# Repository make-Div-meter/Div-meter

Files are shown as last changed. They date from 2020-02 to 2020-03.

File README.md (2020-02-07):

# 概要
ゲーム・アニメ作品「STEINS;GATE（シュタインズ・ゲート）」に登場する「世界線変動率計測器≪ダイバージェンスメーター≫」を製作する。

## 開発スケジュール
### 第1段階　2020年3月31日
ニキシー管に任意の数字を表示できる状態にする。

### 第2段階
時計・カレンダー機能の実装。

### 第3段階
外部端末とBluetooth等の無線通信を用いて接続し、任意に表示を変化させることができる。

## 表示モード
複数の機能を持たせる。
### DGモード
劇中に登場するダイバージェンスメーターと同じように世界線変動率を8桁のニキシー管に表示する。
### 時計モード
時計としての表示を行う。
表示フォーマットは「HH.mm.ss」
### カレンダーモード
カレンダーとしての表示を行う。
表示フォーマットは「MM.dd...」

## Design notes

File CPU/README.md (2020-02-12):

# CPU
マイコン:ESP32<br>
動作電圧:3.3V<br>

Android appとBluetoothで接続する。<br>
appからESPへの送信データは以下の通り

|フォーマット|説明|
|:-:|:-:|
|SET NUM|数値を即座にNUMに変更する|
|RAND NUM|数値をランダムに切り替えながらNUMに変更する|

Bluetoothシリアル経由で取得した値(整数部1桁+小数点+小数部6桁)をUART経由でGPUに送る。

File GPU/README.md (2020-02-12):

# GPU
ニキシー管をダイナミック点灯させるマイコン
CPUとシリアル通信を行い，内部レジスタに値を保存する。またその内容をニキシー管に表示する．内部レジスタに保存した値はCPUから新しい値が送られてくるまで表示され続ける。

## 要求スペック
### 動作クロック
未定
### ピン数
ニキシー管制御　3+4
I2C　2
UART 2
## 動作電圧
3.3V

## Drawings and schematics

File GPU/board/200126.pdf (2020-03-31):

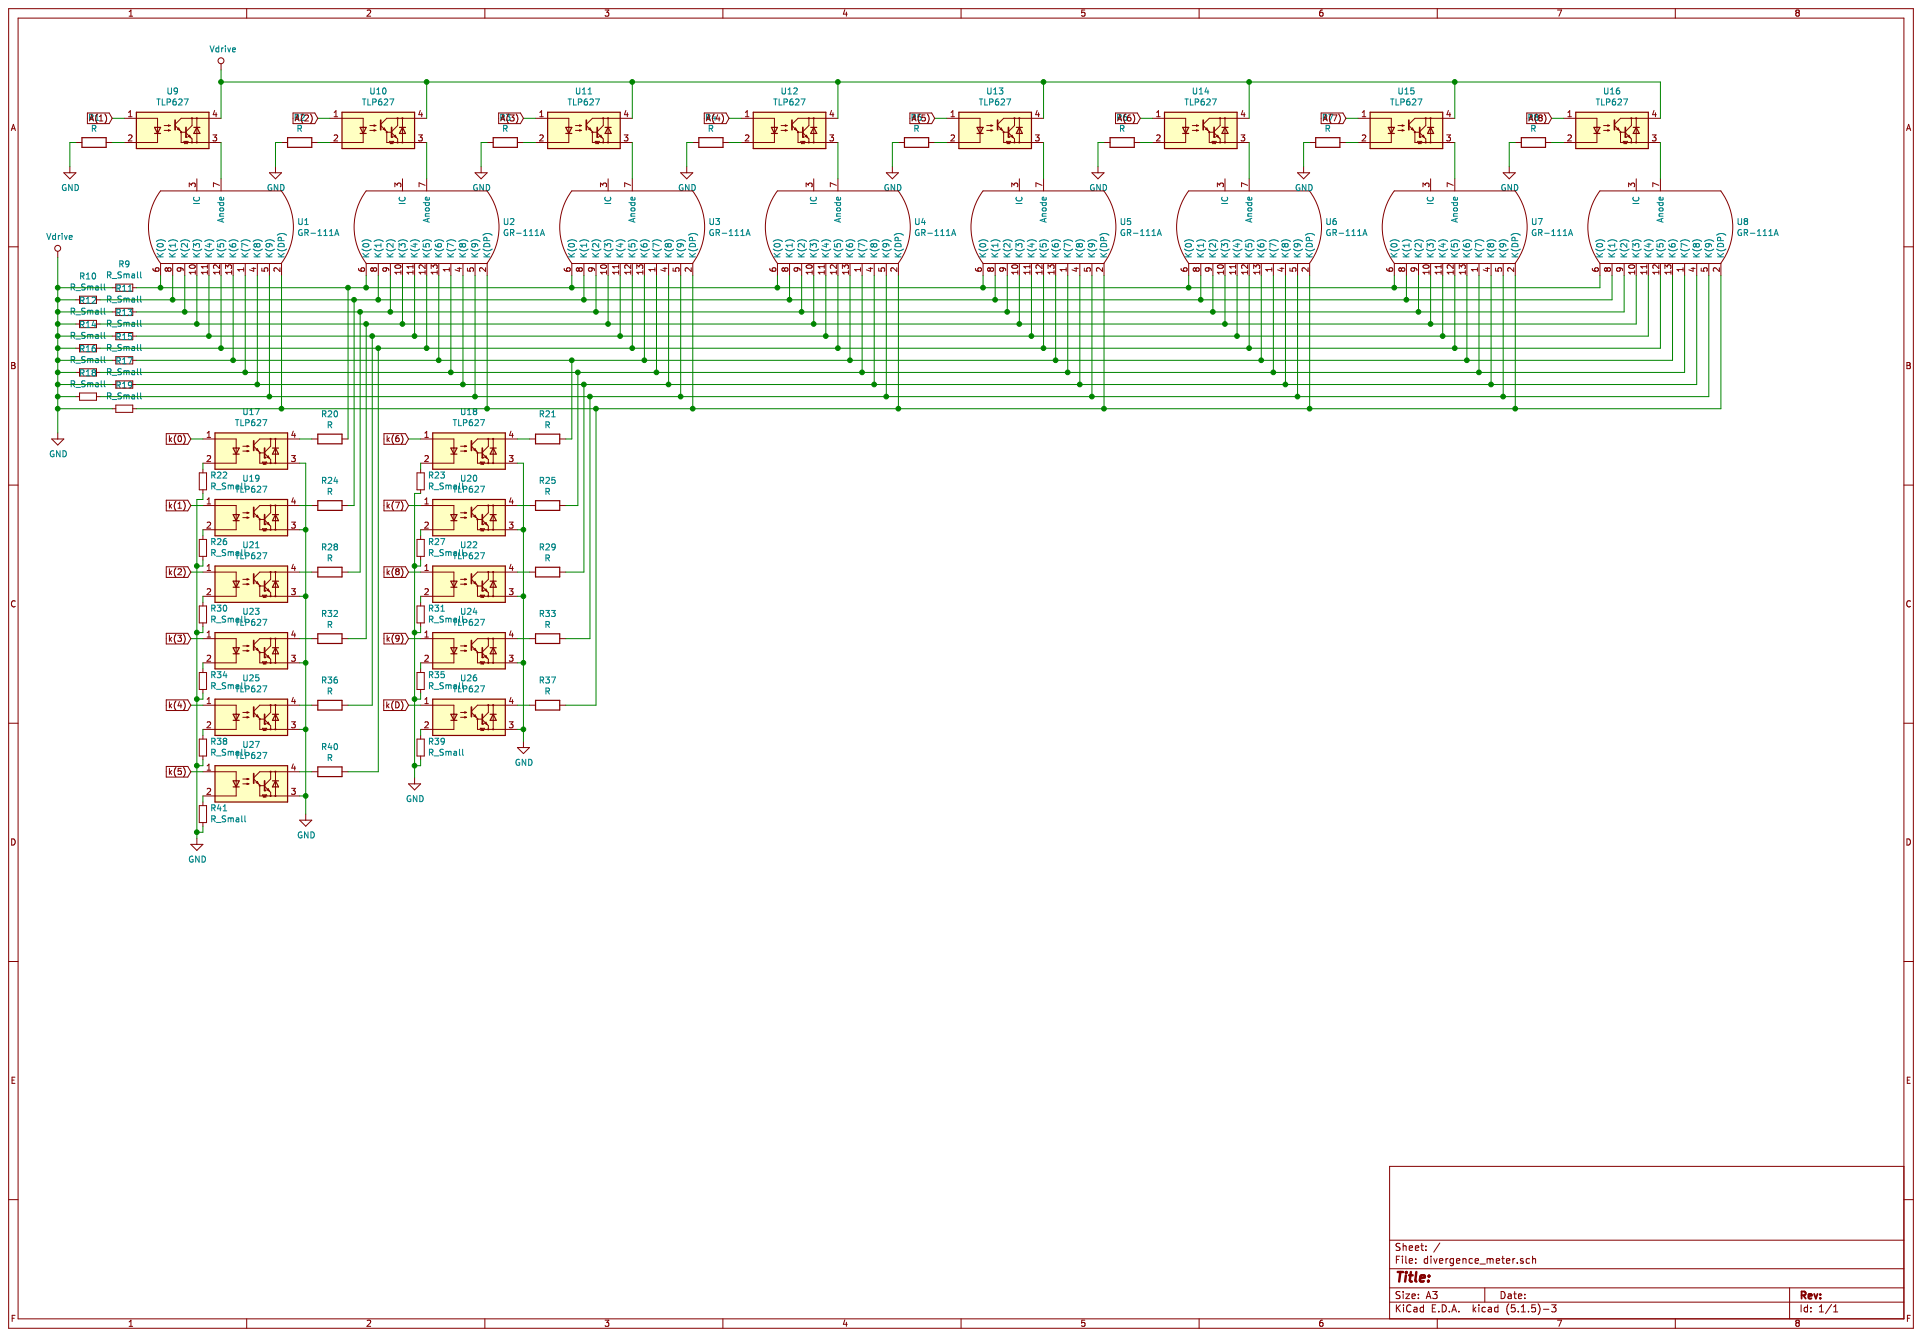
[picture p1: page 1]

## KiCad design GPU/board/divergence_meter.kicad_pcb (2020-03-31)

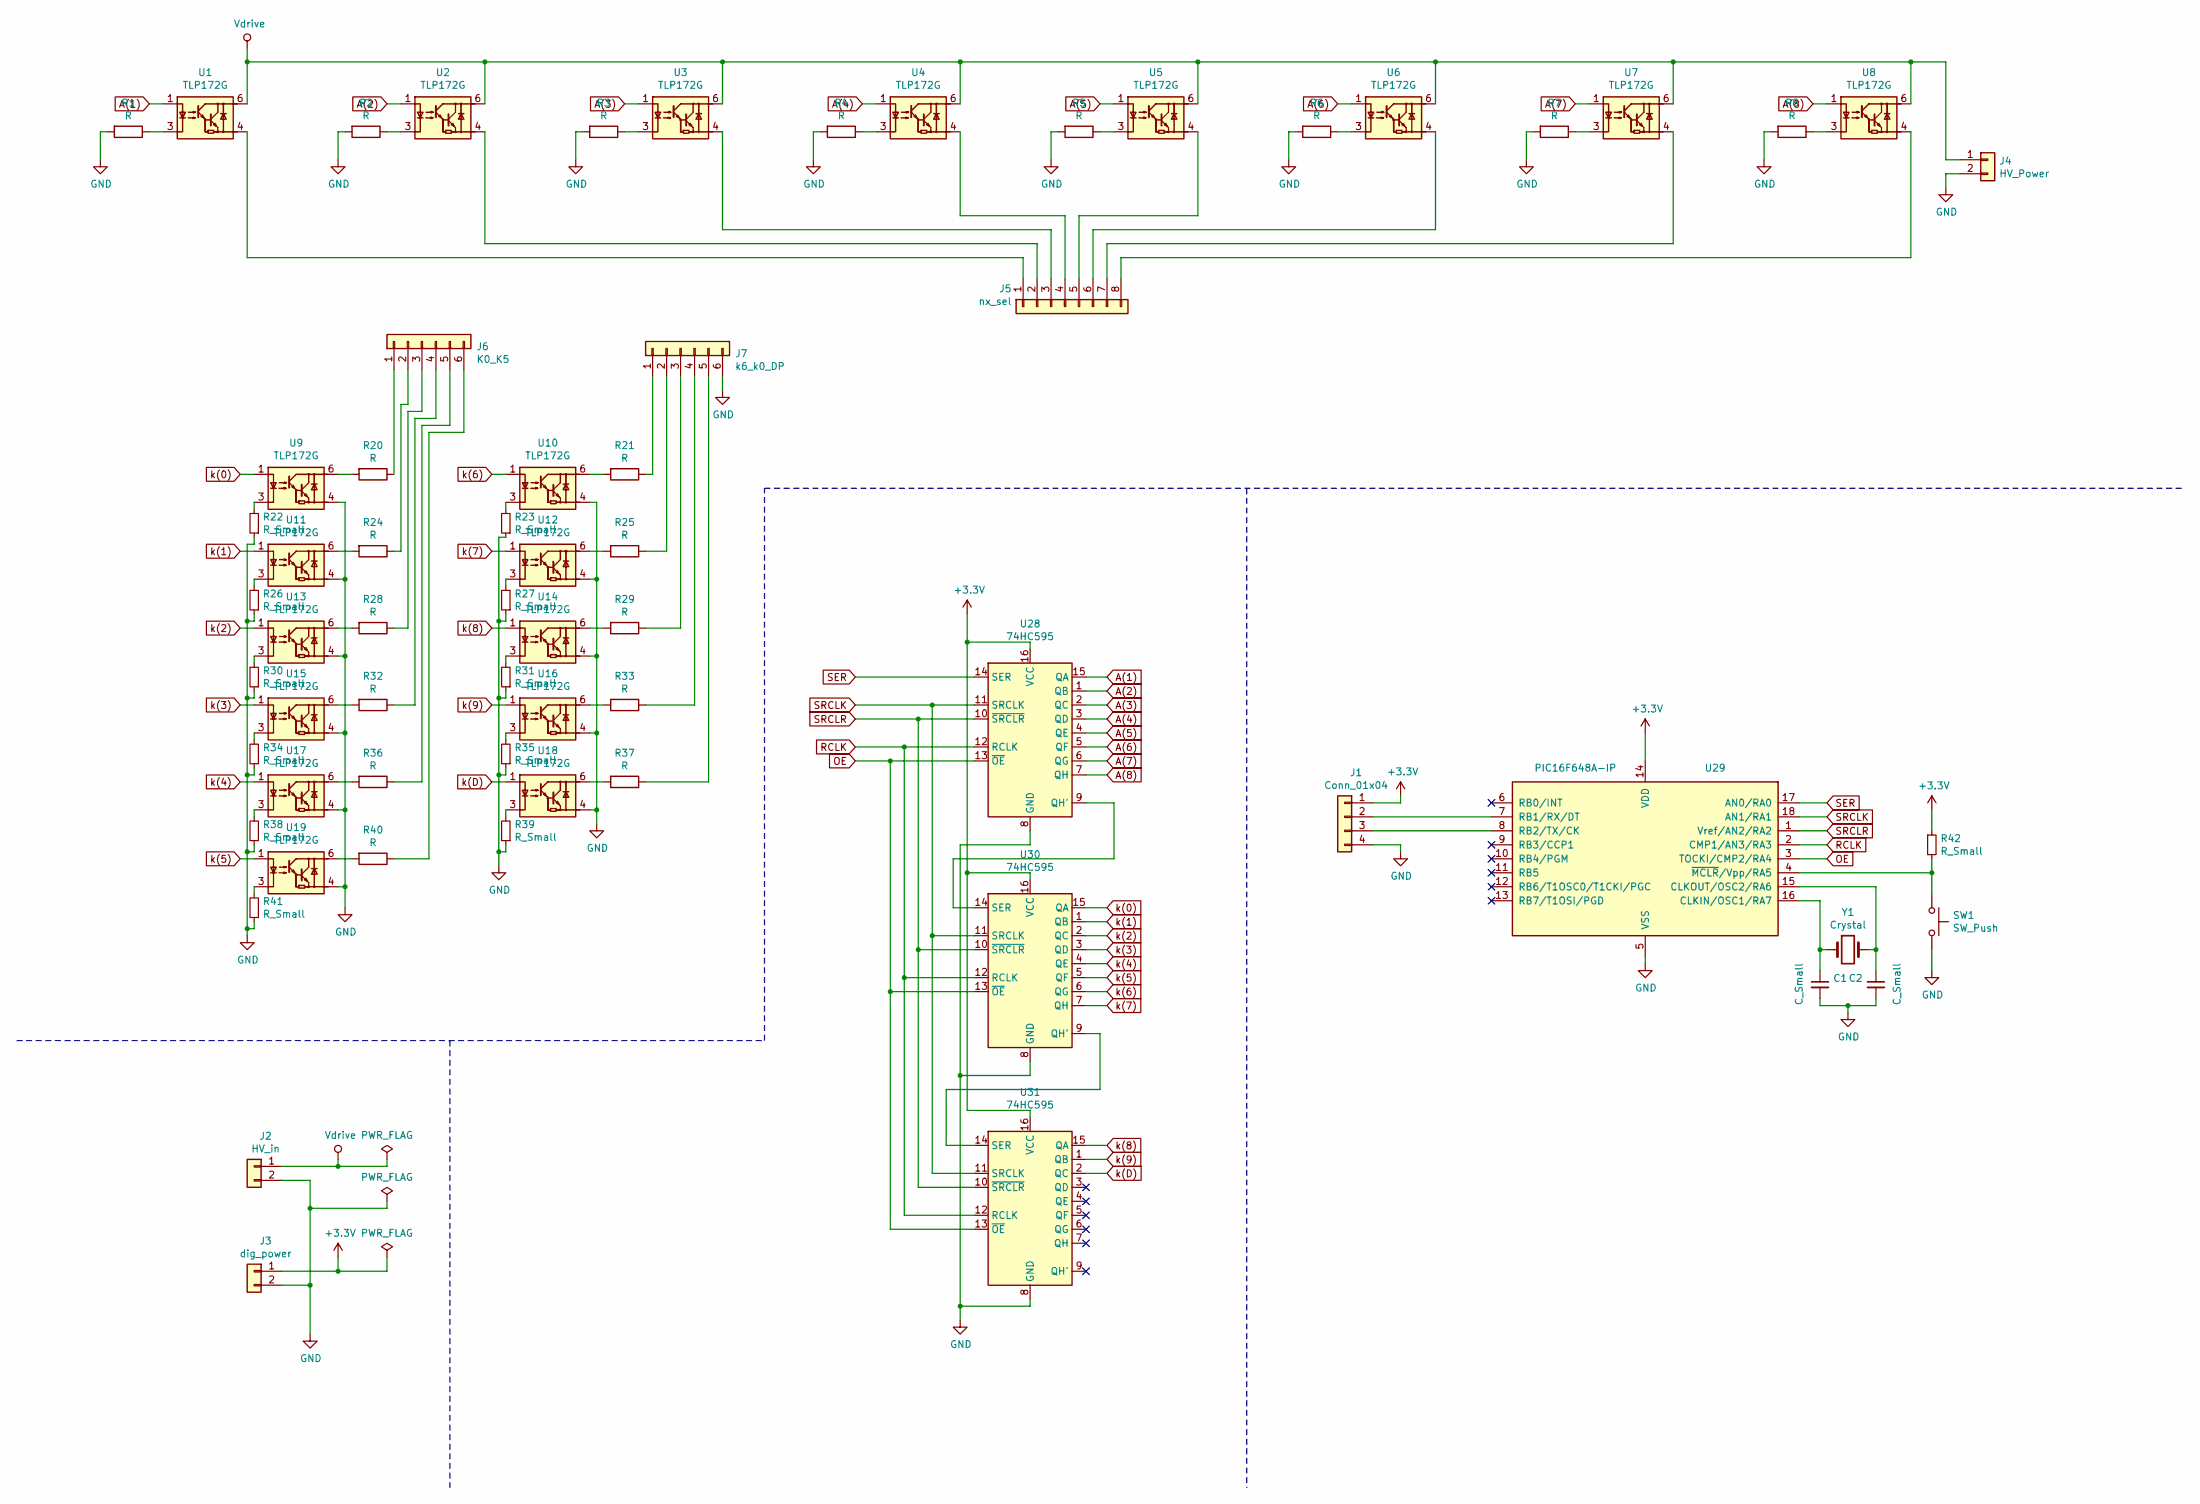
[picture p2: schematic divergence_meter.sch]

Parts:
C1, C2: C_Small; C_0603_1608Metric_Pad1.05x0.95mm_HandSolder
J1: Conn_01x04; PinHeader_1x04_P2.54mm_Vertical
J2: HV_in; PinHeader_1x02_P2.54mm_Vertical
J3: dig_power; PinHeader_1x02_P2.54mm_Vertical
J4: HV_Power; PinHeader_1x02_P2.54mm_Vertical
J5: nx_sel; PinHeader_1x08_P2.54mm_Vertical
J6: K0_K5; PinHeader_1x06_P2.54mm_Vertical
J7: k6_k0_DP; PinHeader_1x06_P2.54mm_Vertical
R1, R2, R3, R4, R5, R6, R7, R8, R20, R21, R24, R25, R28, R29, R32, R33, R36, R37, R40: R; R_0603_1608Metric_Pad1.05x0.95mm_HandSolder
R22, R23, R26, R27, R30, R31, R34, R35, R38, R39, R41, R42: R_Small; R_0603_1608Metric_Pad1.05x0.95mm_HandSolder
SW1: SW_Push; SW_PUSH_6mm_H5mm
U1, U2, U3, U4, U5, U6, U7, U8, U9, U10, U11, U12, U13, U14, U15, U16, U17, U18, U19: TLP172G; DIP-5-6_W8.89mm_SMDSocket_LongPads
U28, U30, U31: 74HC595; SOP-16_4.55x10.3mm_P1.27mm
U29: PIC16F648A-IP; SOIC-18W_7.5x11.6mm_P1.27mm
Y1: Crystal; Crystal_SMD_HC49-SD_HandSoldering

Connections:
+3V3: J1.1, J3.1, R42.1, U28.16 (VCC), U29.14 (VDD), U30.16 (VCC), U31.16 (VCC)
A(1): U1.1, U28.15 (QA)
A(2): U2.1, U28.1 (QB)
A(3): U3.1, U28.2 (QC)
A(4): U4.1, U28.3 (QD)
A(5): U5.1, U28.4 (QE)
A(6): U6.1, U28.5 (QF)
A(7): U7.1, U28.6 (QG)
A(8): U8.1, U28.7 (QH)
GND: C1.2, C2.2, J1.4, J2.2, J3.2, J4.2, J7.6, R1.2, R2.2, R3.2, R4.2, R5.2, R6.2, R7.2, R8.2, R22.1, R23.1, R26.1, R27.1, R30.1, R31.1, R34.1, R35.1, R38.1, R39.1, R41.1, SW1.2, U9.4, U10.4, U11.4, U12.4, U13.4, U14.4, U15.4, U16.4, U17.4, U18.4, U19.4, U28.8 (GND), U29.5 (VSS), U30.8 (GND), U31.8 (GND)
unnamed: C1.1, U29.16 (CLKIN/OSC1/RA7), Y1.1
unnamed: C2.1, U29.15 (CLKOUT/OSC2/RA6), Y1.2
unnamed: J1.2, U29.7 (RB1/RX/DT)
unnamed: J1.3, U29.8 (RB2/TX/CK)
unnamed: J5.1, U1.4
unnamed: J5.2, U2.4
unnamed: J5.3, U3.4
unnamed: J5.4, U4.4
unnamed: J5.5, U5.4
unnamed: J5.6, U6.4
unnamed: J5.7, U7.4
unnamed: J5.8, U8.4
unnamed: J6.1, R20.1
unnamed: J6.2, R24.1
unnamed: J6.3, R28.1
unnamed: J6.4, R32.1
unnamed: J6.5, R36.1
unnamed: J6.6, R40.1
unnamed: J7.1, R21.1
unnamed: J7.2, R25.1
unnamed: J7.3, R29.1
unnamed: J7.4, R33.1
unnamed: J7.5, R37.1
unnamed: R1.1, U1.3
unnamed: R2.1, U2.3
unnamed: R3.1, U3.3
unnamed: R4.1, U4.3
unnamed: R5.1, U5.3
unnamed: R6.1, U6.3
unnamed: R7.1, U7.3
unnamed: R8.1, U8.3
unnamed: R20.2, U9.6
unnamed: R21.2, U10.6
unnamed: R22.2, U9.3
unnamed: R23.2, U10.3
unnamed: R24.2, U11.6
unnamed: R25.2, U12.6
unnamed: R26.2, U11.3
unnamed: R27.2, U12.3
unnamed: R28.2, U13.6
unnamed: R29.2, U14.6
unnamed: R30.2, U13.3
unnamed: R31.2, U14.3
unnamed: R32.2, U15.6
unnamed: R33.2, U16.6
unnamed: R34.2, U15.3
unnamed: R35.2, U16.3
unnamed: R36.2, U17.6
unnamed: R37.2, U18.6
unnamed: R38.2, U17.3
unnamed: R39.2, U18.3
unnamed: R40.2, U19.6
unnamed: R41.2, U19.3
unnamed: R42.2, SW1.1, U29.4 (~MCLR~/Vpp/RA5)
unnamed: U28.9 (QH'), U30.14 (SER)
unnamed: U30.9 (QH'), U31.14 (SER)
OE: U28.13 (~OE), U29.3 (TOCKI/CMP2/RA4), U30.13 (~OE), U31.13 (~OE)
RCLK: U28.12 (RCLK), U29.2 (CMP1/AN3/RA3), U30.12 (RCLK), U31.12 (RCLK)
SER: U28.14 (SER), U29.17 (AN0/RA0)
SRCLK: U28.11 (SRCLK), U29.18 (AN1/RA1), U30.11 (SRCLK), U31.11 (SRCLK)
SRCLR: U28.10 (~SRCLR), U29.1 (Vref/AN2/RA2), U30.10 (~SRCLR), U31.10 (~SRCLR)
Vdrive: J2.1, J4.1, U1.6, U2.6, U3.6, U4.6, U5.6, U6.6, U7.6, U8.6
k(0): U9.1, U30.15 (QA)
k(1): U11.1, U30.1 (QB)
k(2): U13.1, U30.2 (QC)
k(3): U15.1, U30.3 (QD)
k(4): U17.1, U30.4 (QE)
k(5): U19.1, U30.5 (QF)
k(6): U10.1, U30.6 (QG)
k(7): U12.1, U30.7 (QH)
k(8): U14.1, U31.15 (QA)
k(9): U16.1, U31.1 (QB)
k(D): U18.1, U31.2 (QC)

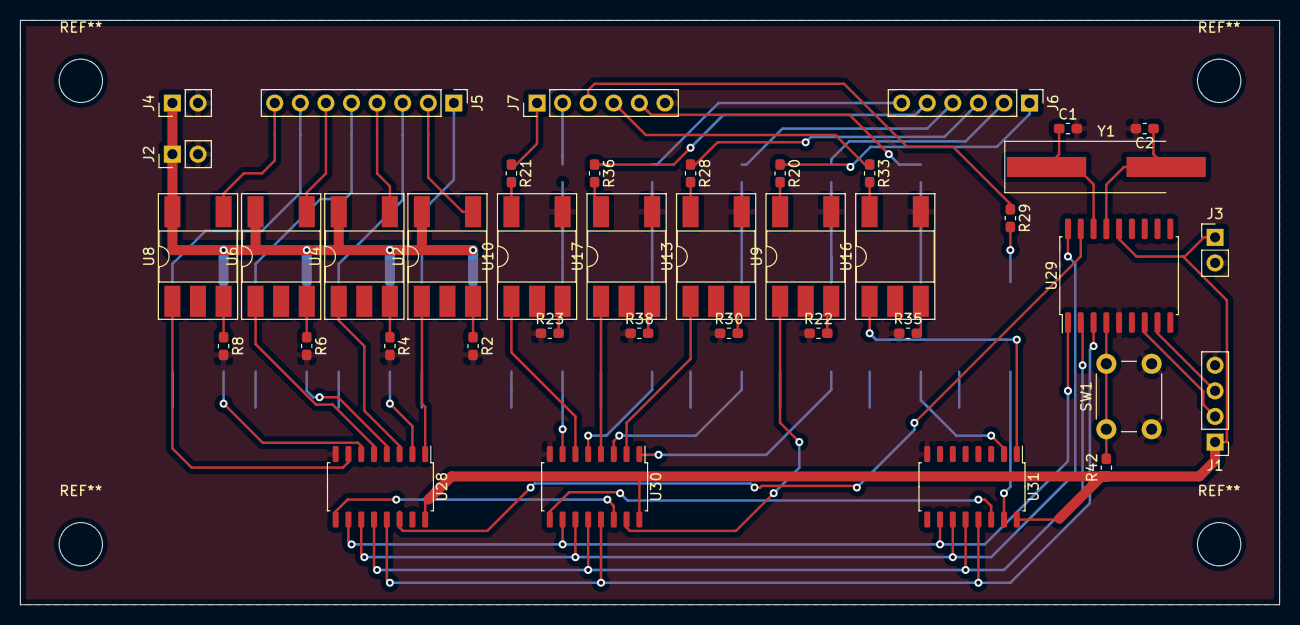
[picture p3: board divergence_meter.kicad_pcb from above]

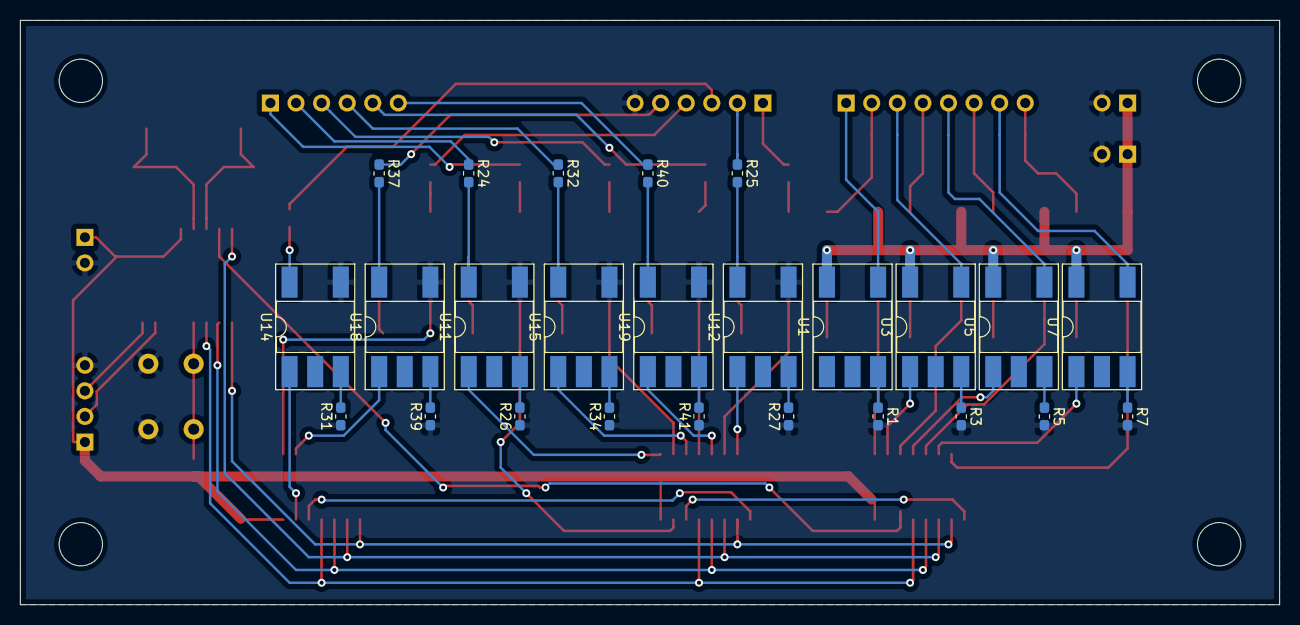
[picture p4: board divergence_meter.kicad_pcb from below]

Board: 2 copper layers, 125.0 x 58.0 mm, 65 parts (25 on the bottom side), 83 nets.
